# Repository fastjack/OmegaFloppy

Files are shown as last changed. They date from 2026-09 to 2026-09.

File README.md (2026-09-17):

# ΩFloppy

A modernized version of XUM1541 with USB-C. Based on the design of the [ZoomFloppy](https://github.com/go4retro/ZoomFloppy) but stripped of all the "weird" connectors.

## Images
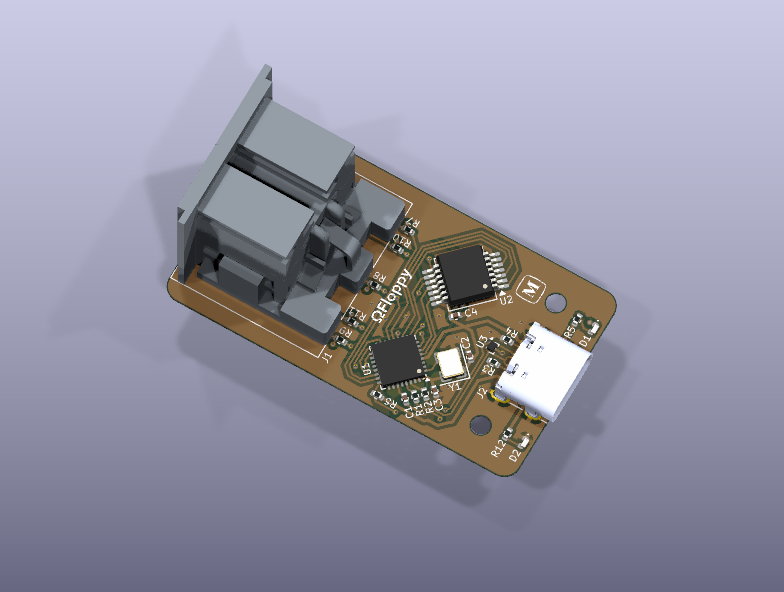
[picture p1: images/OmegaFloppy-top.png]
PCB top

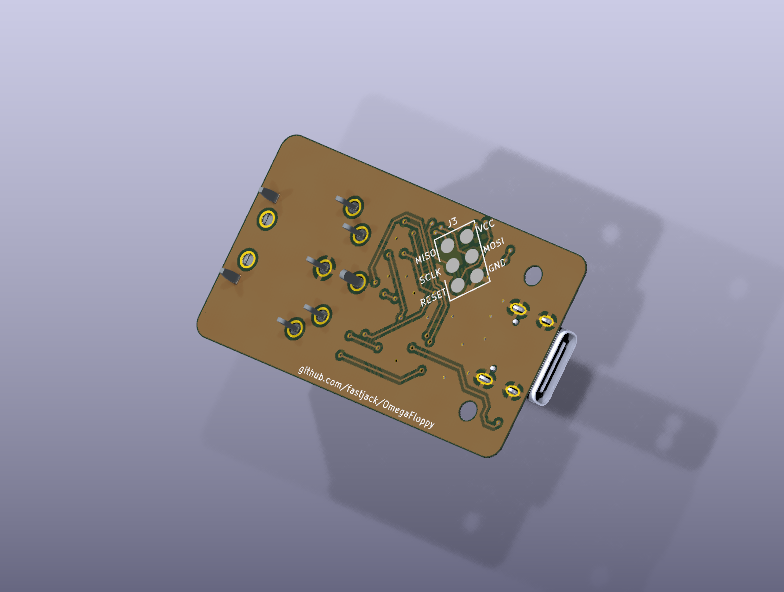
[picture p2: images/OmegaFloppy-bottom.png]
PCB bottom


Yes, I am aware that the two pins of the DIN connector do not line up with the footprint. This is a problem with Lumberg's CAD model (I contacted them about it). I have [verified](images/footprint-test.jpeg) the footprint with the real connector.

## WARNING!
This PCB is still untested. First PCBs have been ordered.

This KiCAD project was created with a nightly build of KiCAD 10.99. The current release of KiCAD 10 (Version 10.0.6 as of this writing) will most certainly not open the project.

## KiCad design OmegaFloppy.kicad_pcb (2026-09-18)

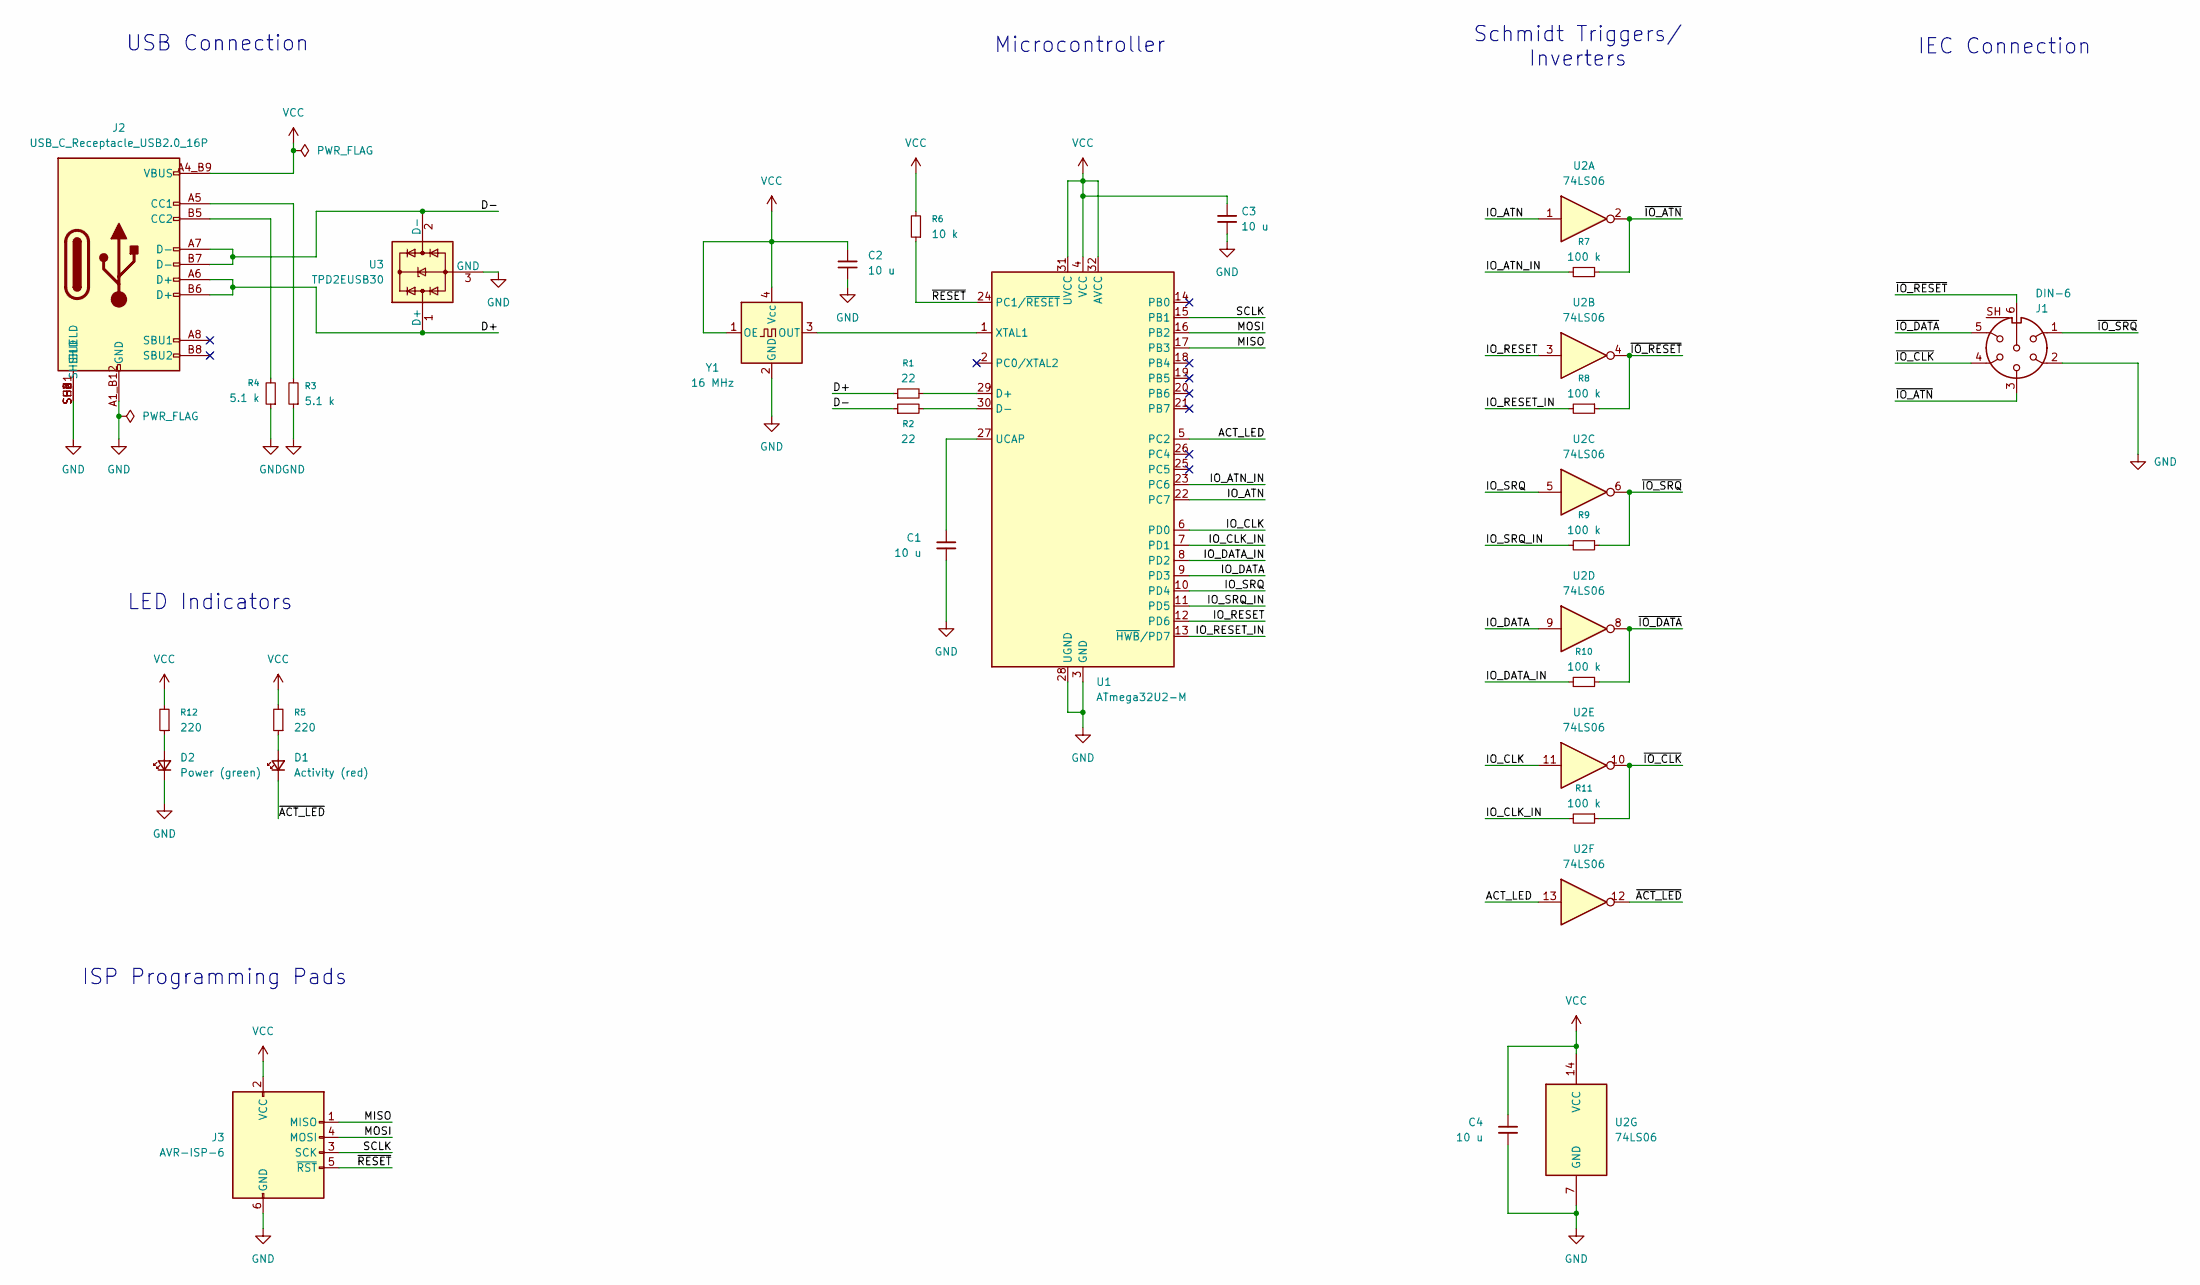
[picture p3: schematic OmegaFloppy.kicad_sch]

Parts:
C1, C2, C3, C4: 10 u; C_0402_1005Metric; MPN GRM155R61A106ME11D; LCSC C408132
D1: Activity (red); LED_0402_1005Metric; MPN IN-S42DS5R; LCSC C6968971
D2: Power (green); LED_0402_1005Metric; MPN IN-S42DS5G; LCSC C6968971
J1: DIN-6; DIN45322; MPN 0105 06
J2: USB_C_Receptacle_USB2.0_16P; AMPHENOL_10155435-00011LF; MPN 10155435-00011LF; LCSC C5409177
J3: AVR-ISP-6; AVRISP_Pogo
R1, R2: 22; R_0402_1005Metric; MPN RK73H1ETTP22R0F; LCSC C159964
R3, R4: 5.1 k; R_0402_1005Metric; MPN RN73R1ETTP5101B25; LCSC C2480097
R5, R12: 220; R_0402_1005Metric; MPN RN73R1ETTP2200F50; LCSC C2499122
R6: 10 k; R_0402_1005Metric; MPN RN73R1ETTP1002B25; LCSC C2480096
R7, R8, R9, R10, R11: 100 k; R_0402_1005Metric; MPN RN73R1ETTP1003B25; LCSC C2480096
U1: ATmega32U2-M; QFN-32-1EP_5x5mm_P0.5mm_EP3.1x3.1mm; MPN ATMEGA32U2-MU; LCSC C57345
U2: 74LS06; SSOP-14_5.3x6.2mm_P0.65mm; MPN SN74LS06DBR; LCSC C2682072
U3: TPD2EUSB30; Texas_DRT-3; MPN TPD2EUSB30ADRTR; LCSC C94934
Y1: 16 MHz; Crystal_SMD_3225-4Pin_3.2x2.5mm; MPN SX3M16.000A10F20TNN; LCSC C41361431

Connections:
/ACT_LED: U1.5 (PC2), U2.13
/D+: J2.A6 (D+), J2.B6 (D+), R1.1, U3.1 (D+)
/D-: J2.A7 (D-), J2.B7 (D-), R2.1, U3.2 (D-)
/IO_ATN: U1.22 (PC7), U2.1
/IO_ATN_IN: R7.2, U1.23 (PC6)
/IO_CLK: U1.6 (PD0), U2.11
/IO_CLK_IN: R11.2, U1.7 (PD1)
/IO_DATA: U1.9 (PD3), U2.9
/IO_DATA_IN: R10.2, U1.8 (PD2)
/IO_RESET: U1.12 (PD6), U2.3
/IO_RESET_IN: R8.2, U1.13 (~HWB/PD7)
/IO_SRQ: U1.10 (PD4), U2.5
/IO_SRQ_IN: R9.2, U1.11 (PD5)
/MISO: J3.1 (MISO), U1.17 (PB3)
/MOSI: J3.4 (MOSI), U1.16 (PB2)
/SCLK: J3.3 (SCK), U1.15 (PB1)
/~ACT_LED: D1.1 (K), U2.12
/~IO_ATN: J1.3, R7.1, U2.2
/~IO_CLK: J1.4, R11.1, U2.10
/~IO_DATA: J1.5, R10.1, U2.8
/~IO_RESET: J1.6, R8.1, U2.4
/~IO_SRQ: J1.1, R9.1, U2.6
/~RESET: J3.5 (~RST), R6.1, U1.24 (PC1/~RESET)
GND: C1.2, C2.2, C3.2, C4.2, D2.1 (K), J1.2, J2.A1_B12 (GND), J2.B1_A12 (GND), J2.SH1 (SHIELD), J2.SH2 (SHIELD), J2.SH3 (SHIELD), J2.SH4 (SHIELD), J3.6 (GND), R3.1, R4.1, U1.3 (GND), U1.28 (UGND), U1.33 (GND), U2.7 (GND), U3.3 (GND), Y1.2 (GND)
unnamed: D1.2 (A), R5.1
unnamed: D2.2 (A), R12.1
unnamed: J2.A5 (CC1), R3.2
unnamed: J2.B5 (CC2), R4.2
unnamed: R1.2, U1.29 (D+)
unnamed: R2.2, U1.30 (D-)
unnamed: C1.1, U1.27 (UCAP)
unnamed: U1.1 (XTAL1), Y1.3 (OUT)
VCC: C2.1, C3.1, C4.1, J2.A4_B9 (VBUS), J2.B4_A9 (VBUS), J3.2 (VCC), R5.2, R6.2, R12.2, U1.4 (VCC), U1.31 (UVCC), U1.32 (AVCC), U2.14 (VCC), Y1.1 (OE), Y1.4 (Vcc)

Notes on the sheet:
LED Indicators
ISP Programming Pads
USB Connection
Schmidt Triggers/ Inverters
IEC Connection
Microcontroller

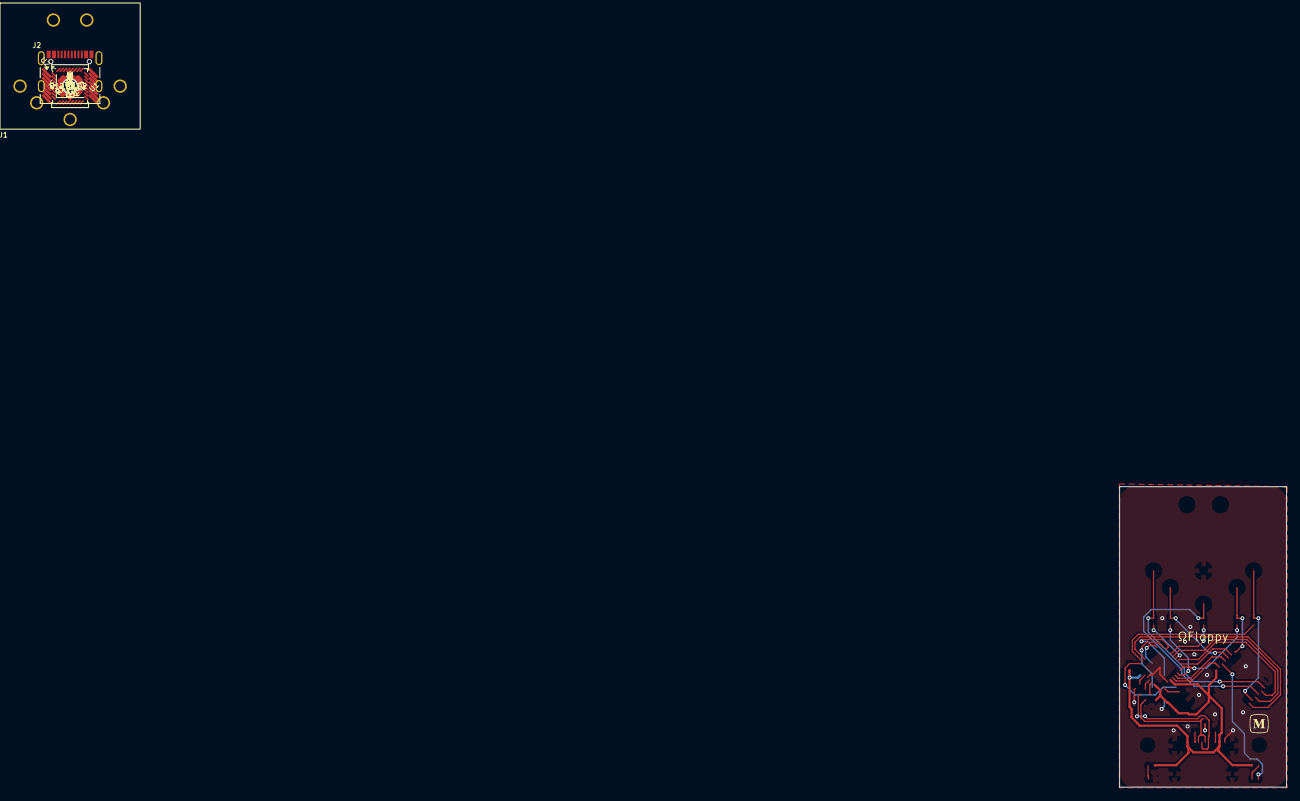
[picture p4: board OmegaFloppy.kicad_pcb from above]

Board: 2 copper layers, 25.0 x 45.0 mm, 25 parts (1 on the bottom side), 33 nets.

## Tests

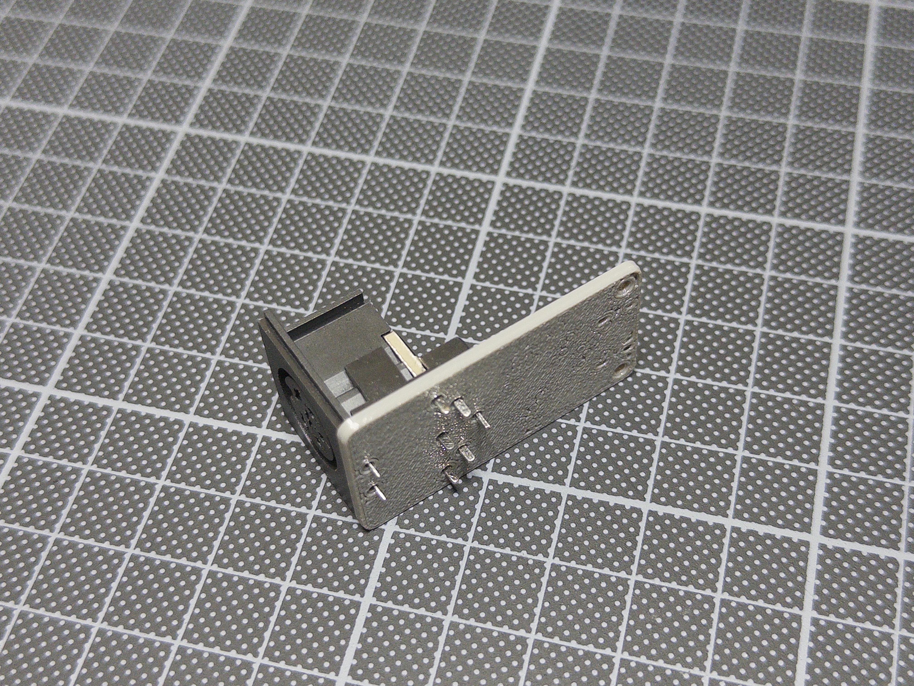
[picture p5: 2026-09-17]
images/footprint-test.jpeg

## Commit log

2026-09-16 added project link
    [OmegaFloppy.kicad_pcb]
2026-09-17 fixed missing connection on IEC port
    [OmegaFloppy.kicad_pcb, OmegaFloppy.kicad_sch]
2026-09-17 cleaned up the schematics
    [OmegaFloppy.kicad_sch]
2026-09-18 added missing input pins
    [OmegaFloppy.kicad_pcb, OmegaFloppy.kicad_sch]
